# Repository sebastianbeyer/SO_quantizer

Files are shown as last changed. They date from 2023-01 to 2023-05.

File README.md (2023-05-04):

Kosmo format quantizer based largely on the [kassutronics quantizer](https://store.kassutronics.net/eurorack-diy-c-1/quantizer-p-1). 
I went for a different interface though, where you select the scale via potentiometer and with the second potentiometer (and cv input) you can bias the incoming voltages and therefore 'transpose in scale'. 
It still lacks a few scales.

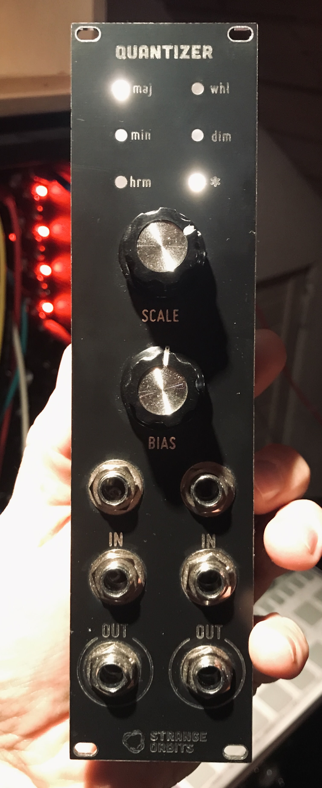
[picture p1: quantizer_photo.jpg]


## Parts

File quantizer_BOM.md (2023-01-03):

# quantizer.kicad_sch BOM

Tue 03 Jan 2023 10:16:02 CET

Generated from schematic by Eeschema 6.0.8-f2edbf62ab~116~ubuntu22.04.1

**Component Count:** 114

| Refs | Qty | Component | Description | Vendor | SKU |
| ----- | --- | ---- | --- | ---- | ---- |
| A1 | 1 | Arduino_Nano_v3.x | Arduino Nano v3.x |  |  |
| C1, C8, C15, C17 | 4 | 470p | Unpolarized capacitor |  |  |
| C2, C9, C16, C18 | 4 | 47p | Unpolarized capacitor |  |  |
| C3, C4, C10, C11 | 4 | 220p | Unpolarized capacitor |  |  |
| C5, C6, C7, C12, C13, C14 | 6 | 1n | Unpolarized capacitor |  |  |
| C19, C20, C25, C26 | 4 | 100n | Unpolarized capacitor |  |  |
| C21, C23, C24 | 3 | 10u | Polarized capacitor | Tayda |  |
| C22 | 1 | 22n | Unpolarized capacitor |  |  |
| D1, D2, D3, D4, D5, D6 | 6 | LED_red | Light emitting diode | Tayda | A-1554 |
| D7, D8 | 2 | 1N5817 | Schottky Barrier Rectifier Diode, DO-41 | Tayda | A-159 |
| J1 | 1 | cv_in_a | Audio Jack, 2 Poles (Mono / TS), Switched T Pole (Normalling) | Tayda | A-1121 |
| J2 | 1 | cv_out_a | Audio Jack, 2 Poles (Mono / TS), Switched T Pole (Normalling) | Tayda | A-1121 |
| J3 | 1 | cv_in_a_aux | Audio Jack, 2 Poles (Mono / TS), Switched T Pole (Normalling) | Tayda | A-1121 |
| J4 | 1 | cv_out_b | Audio Jack, 2 Poles (Mono / TS), Switched T Pole (Normalling) | Tayda | A-1121 |
| J5 | 1 | Conn_01x08_Male | Generic connector, single row, 01x08, script generated (kicad-library-utils/schlib/autogen/connector/) |  |  |
| J6 | 1 | Conn_01x08_Female | Generic connector, single row, 01x08, script generated (kicad-library-utils/schlib/autogen/connector/) |  |  |
| J7 | 1 | cv_in_b_aux | Audio Jack, 2 Poles (Mono / TS), Switched T Pole (Normalling) | Tayda | A-1121 |
| J8 | 1 | cv_in_b | Audio Jack, 2 Poles (Mono / TS), Switched T Pole (Normalling) | Tayda | A-1121 |
| J9 | 1 | Conn_01x06_Male | Generic connector, single row, 01x06, script generated (kicad-library-utils/schlib/autogen/connector/) |  |  |
| J10 | 1 | Conn_01x06_Female | Generic connector, single row, 01x06, script generated (kicad-library-utils/schlib/autogen/connector/) |  |  |
| J11 | 1 | Synth_power_2x5 | Pin header 2.54 mm 2x5 | Tayda | A-2939 |
| JP1, JP2 | 2 | SolderJumper_2_Open | Solder Jumper, 2-pole, open |  |  |
| Q1, Q2, Q3, Q4, Q5, Q6 | 6 | 2N3904 | Small Signal NPN Transistor, TO-92 | Tayda | A-111 |
| R1, R4, R13, R14, R15, R18, R27, R28, R29, R32, R40, R43 | 12 | *10k | Resistor | Tayda |  |
| R2, R16, R30, R41 | 4 | 10k | Resistor | Tayda |  |
| R3, R9, R17, R19, R31, R33, R42, R44, R45, R46, R47, R48, R49, R50 | 14 | 100k | Resistor | Tayda |  |
| R5, R7, R20, R22, R52 | 5 | 15k | Resistor | Tayda |  |
| R6, R8, R21, R23 | 4 | 68k | Resistor | Tayda |  |
| R10, R12, R24, R26, R34, R35, R36, R37, R38, R39 | 10 | 1k | Resistor | Tayda |  |
| R11, R25 | 2 | 1M | Resistor | Tayda |  |
| R51 | 1 | 47k | Resistor | Tayda |  |
| RV1, RV2 | 2 | 10k | Trim-potentiometer | Tayda |  |
| RV3, RV4 | 2 | 10k | Potentiometer | Tayda |  |
| RV5 | 1 | 5k | Trim-potentiometer | Tayda |  |
| U1, U2 | 2 | TL074 | Quad operational amplifier, DIP-14 | Tayda | A-1138 |
| U3 | 1 | LP2951-5.0 | Micropower Voltage Regulators with Shutdown, 100mA, Fixed Output 5.0V, LDO, DIP-8 |  |  |

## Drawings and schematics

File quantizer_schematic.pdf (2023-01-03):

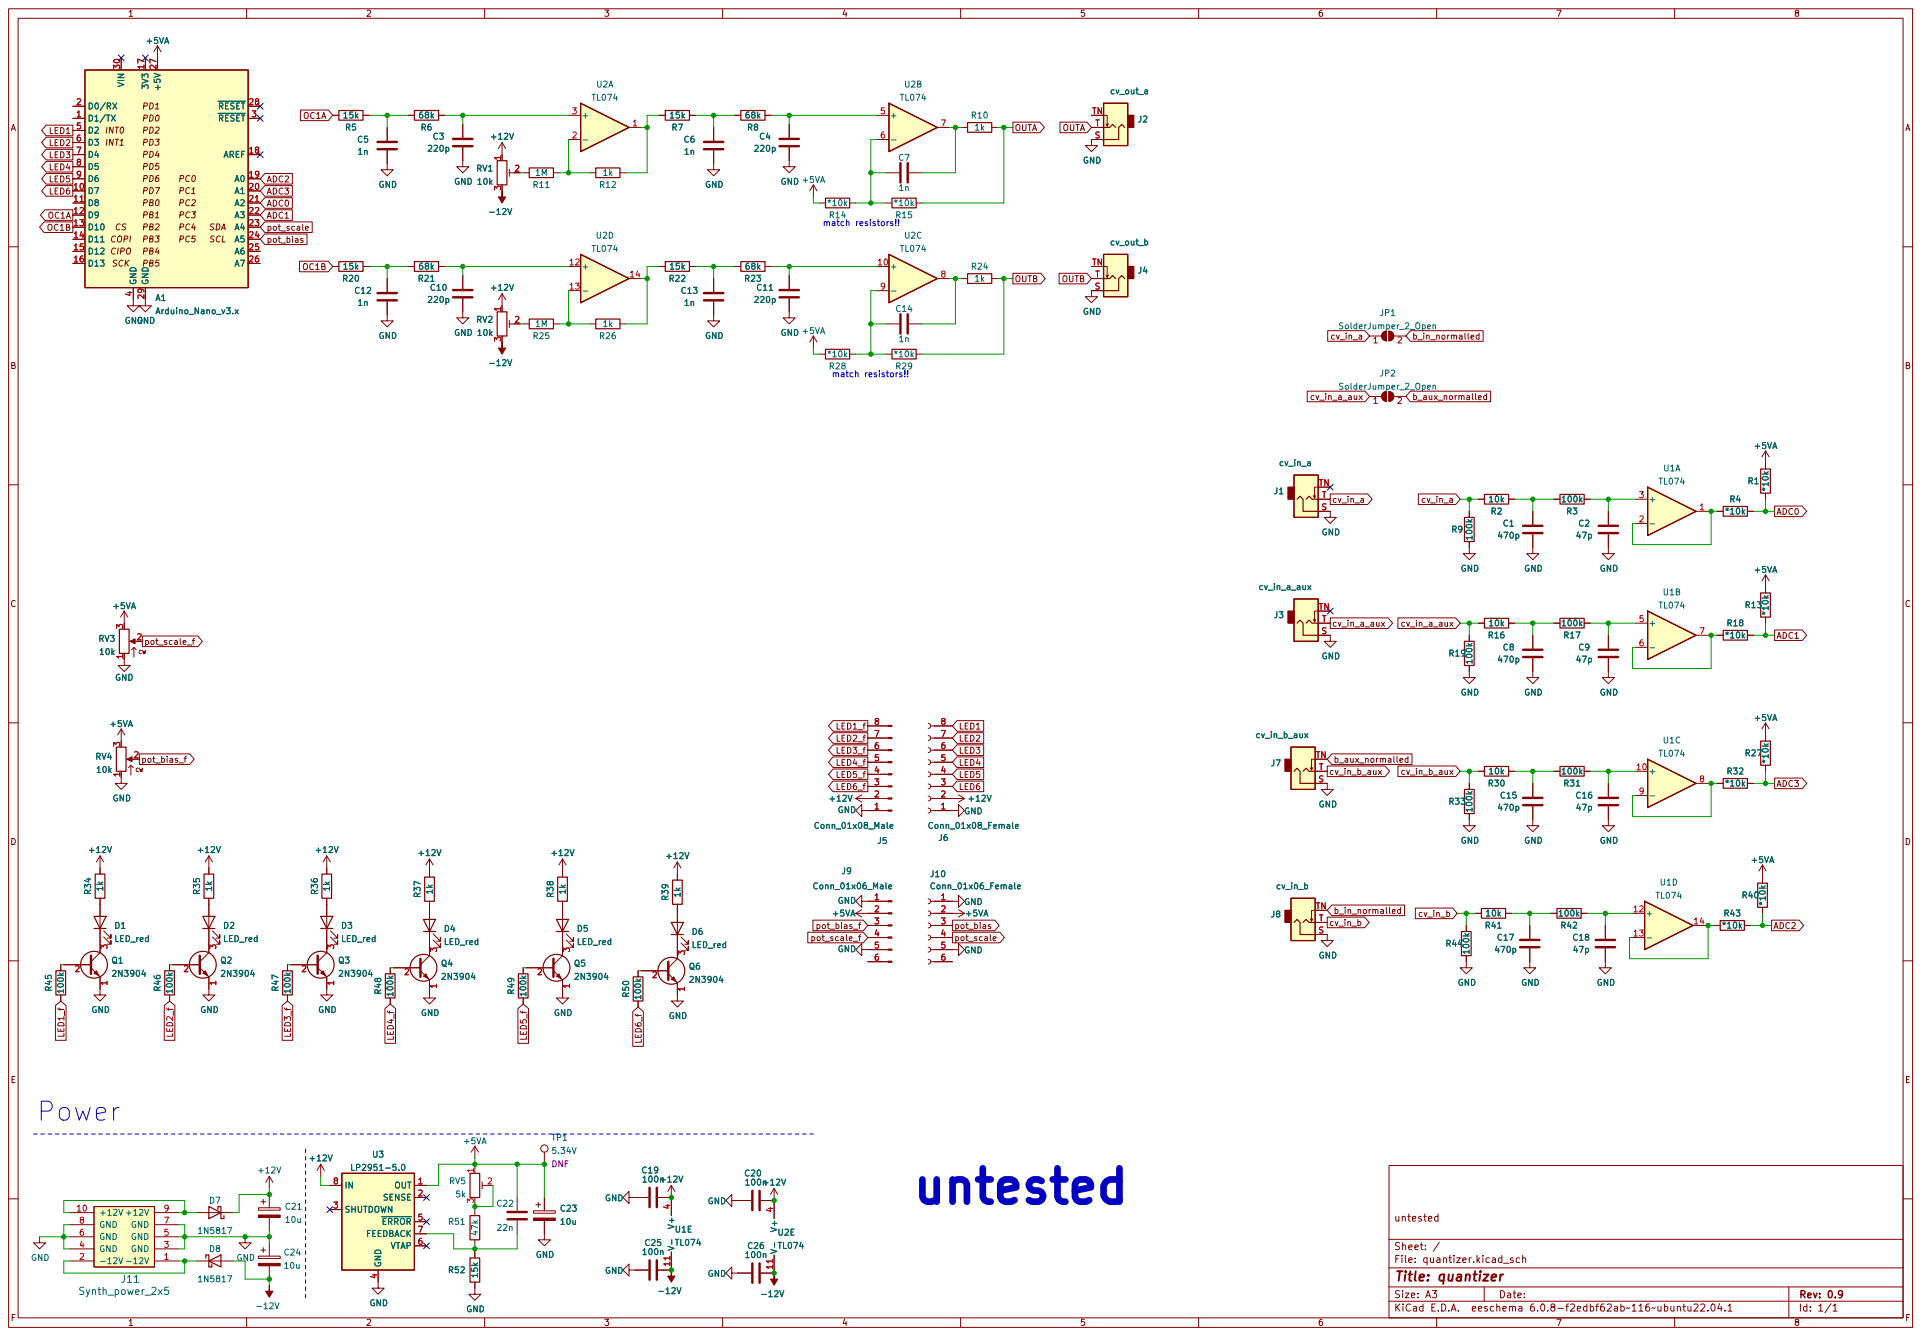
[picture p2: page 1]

match resistors!! match resistors!! GND

File: quantizer.kicad_sch Sheet: / untested

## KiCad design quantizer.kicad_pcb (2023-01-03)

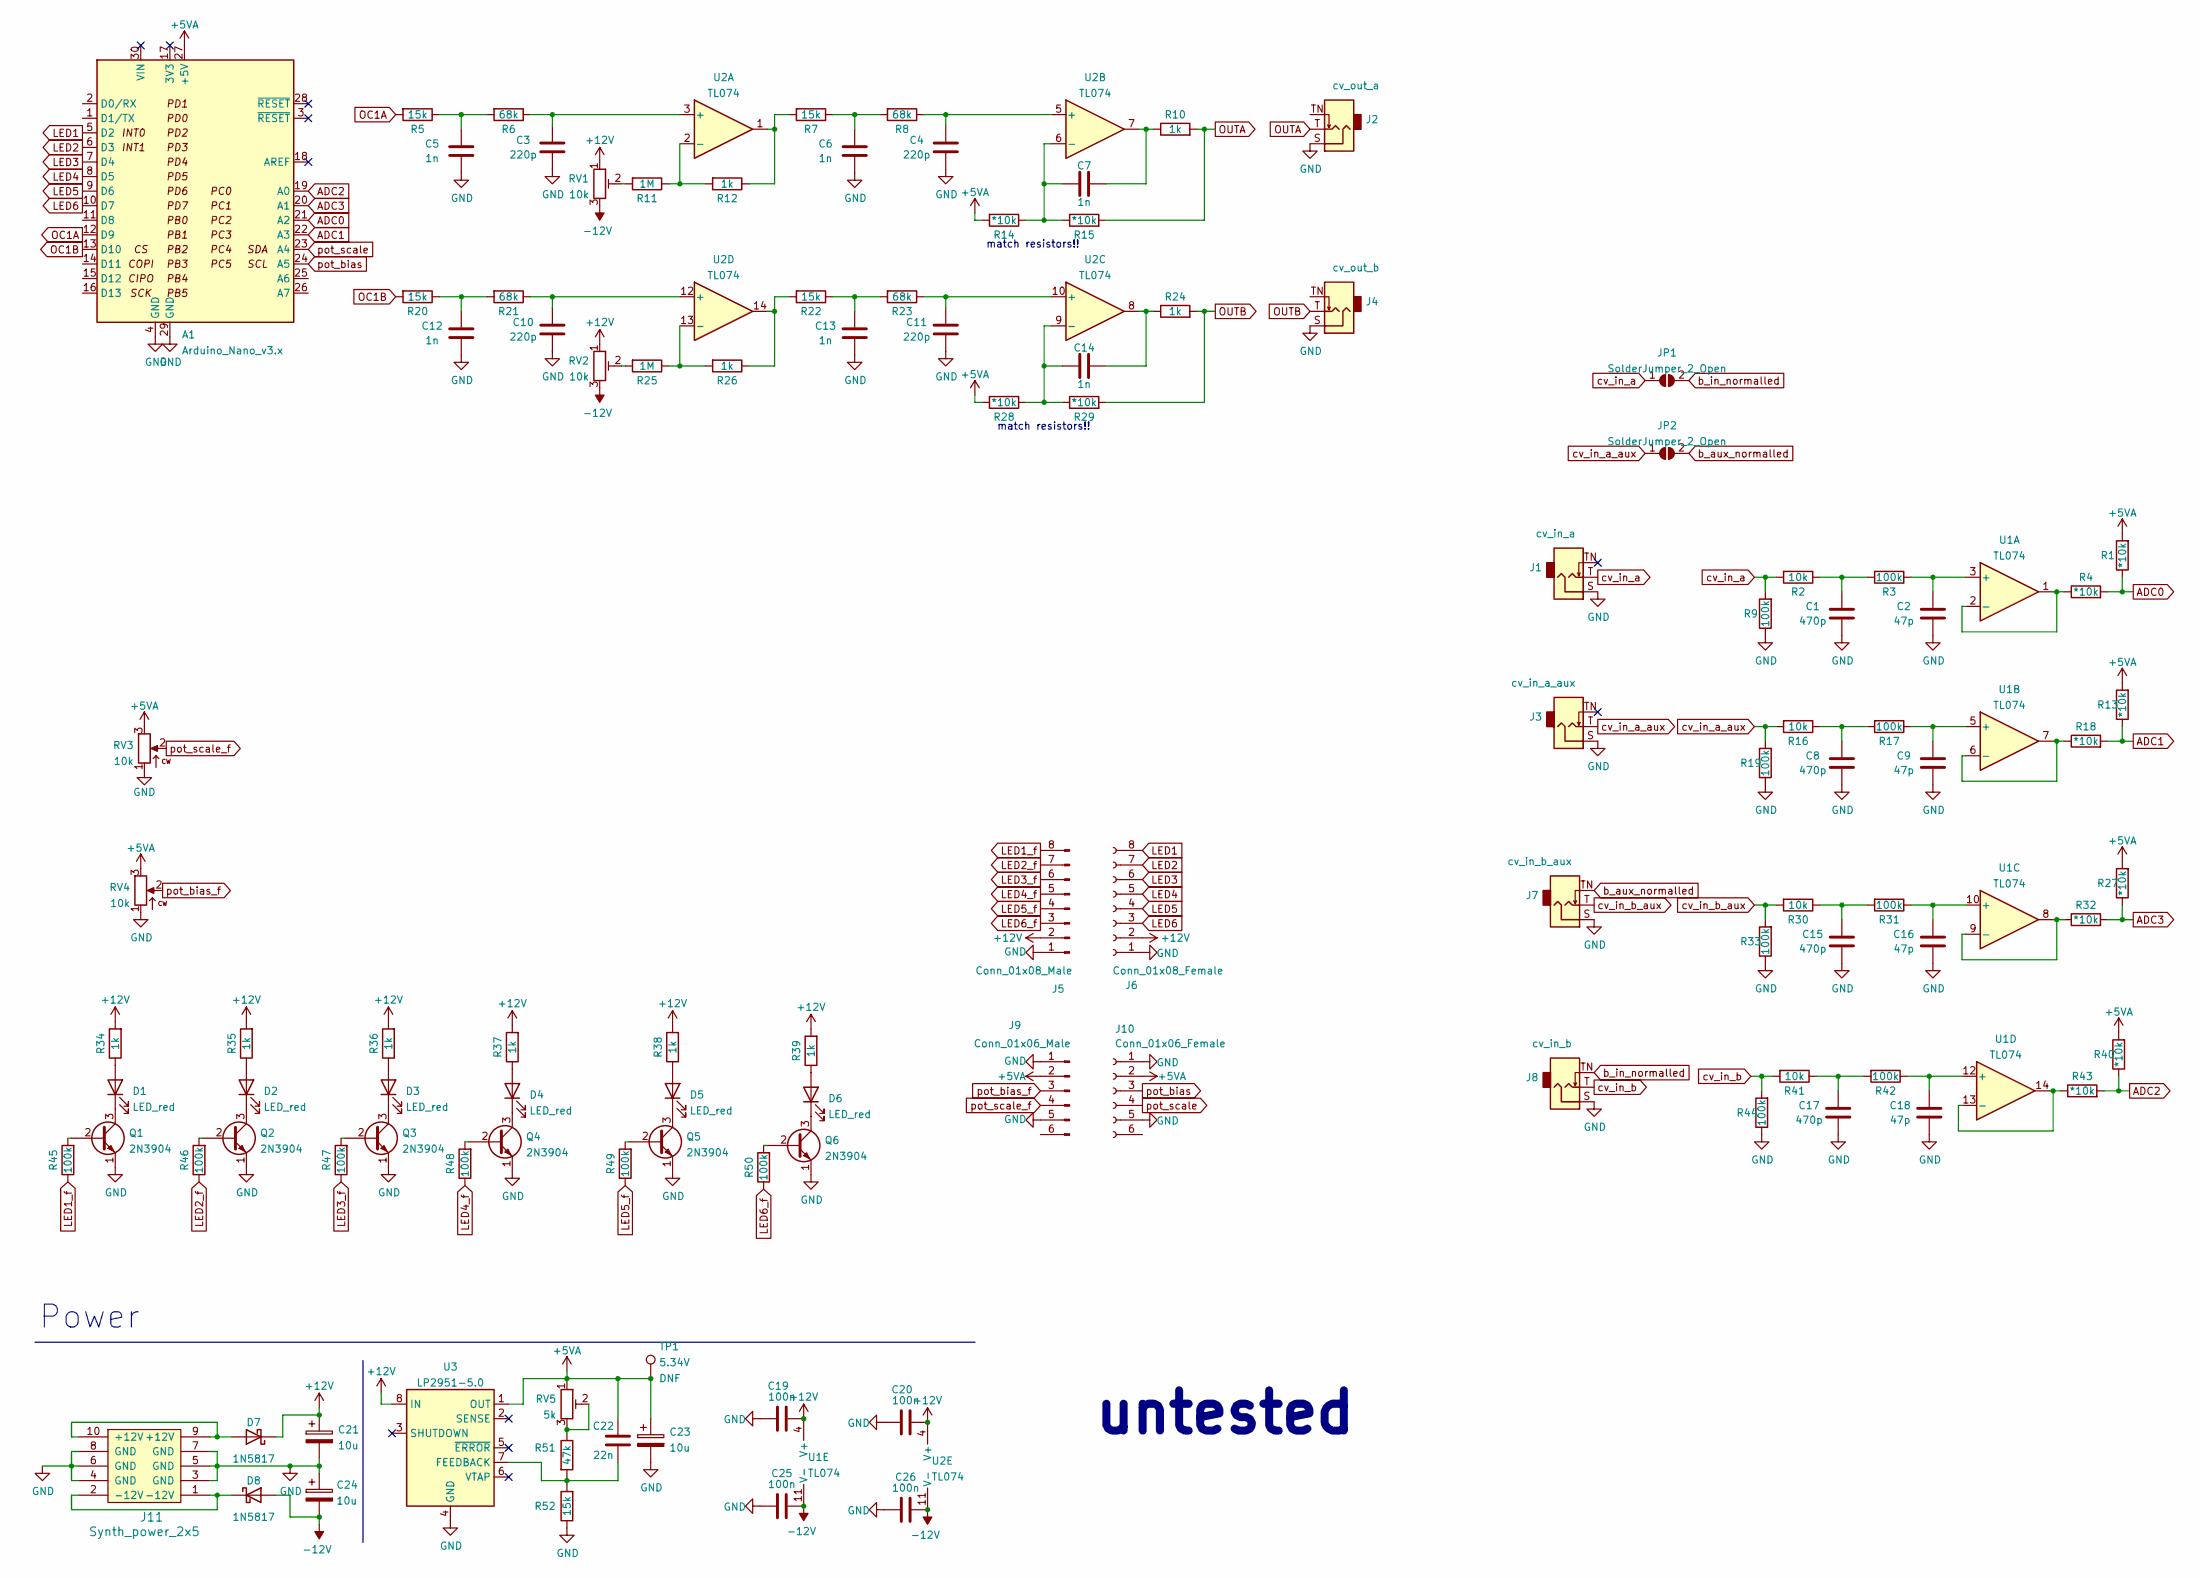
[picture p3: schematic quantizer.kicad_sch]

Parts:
A1: Arduino_Nano_v3.x; Arduino_Nano
C1, C8, C15, C17: 470p; C_Disc_D3.0mm_W1.6mm_P2.50mm
C2, C9, C16, C18: 47p; C_Disc_D3.0mm_W1.6mm_P2.50mm
C3, C4, C10, C11: 220p; C_Disc_D3.0mm_W1.6mm_P2.50mm
C5, C6, C7, C12, C13, C14: 1n; C_Disc_D3.0mm_W1.6mm_P2.50mm
C19, C20, C25, C26: 100n; C_Disc_D3.0mm_W1.6mm_P2.50mm
C21, C23, C24: 10u; CP_Radial_horizontalflat_D5mm_P2.50mm_H10mm_south
C22: 22n; C_Rect_L7.2mm_W2.5mm_P5.00mm_FKS2_FKP2_MKS2_MKP2
D1, D2, D3, D4, D5, D6: LED_red; LED_D3.0mm_FlatTop
D7, D8: 1N5817; D_DO-41_SOD81_P10.16mm_Horizontal
J1: cv_in_a; Jack_6.35mm_PJ_629HAN
J2: cv_out_a; Jack_6.35mm_PJ_629HAN
J3: cv_in_a_aux; Jack_6.35mm_PJ_629HAN
J4: cv_out_b; Jack_6.35mm_PJ_629HAN
J5: Conn_01x08_Male; PinHeader_1x08_P2.54mm_Vertical
J6: Conn_01x08_Female; PinSocket_1x08_P2.54mm_Vertical
J7: cv_in_b_aux; Jack_6.35mm_PJ_629HAN
J8: cv_in_b; Jack_6.35mm_PJ_629HAN
J9: Conn_01x06_Male; PinHeader_1x06_P2.54mm_Vertical
J10: Conn_01x06_Female; PinSocket_1x06_P2.54mm_Vertical
J11: Synth_power_2x5; Power_Header
JP1, JP2: SolderJumper_2_Open; SolderJumper-2_P1.3mm_Open_RoundedPad1.0x1.5mm
Q1, Q2, Q3, Q4, Q5, Q6: 2N3904; TO-92_Inline_Wide
R1, R4, R13, R14, R15, R18, R27, R28, R29, R32, R40, R43: *10k; R_Axial_DIN0207_L6.3mm_D2.5mm_P2.54mm_Vertical
R2, R16, R30, R41: 10k; R_Axial_DIN0207_L6.3mm_D2.5mm_P2.54mm_Vertical
R3, R9, R17, R19, R31, R33, R42, R44, R45, R46, R47, R48, R49, R50: 100k; R_Axial_DIN0207_L6.3mm_D2.5mm_P2.54mm_Vertical
R5, R7, R20, R22, R52: 15k; R_Axial_DIN0207_L6.3mm_D2.5mm_P2.54mm_Vertical
R6, R8, R21, R23: 68k; R_Axial_DIN0207_L6.3mm_D2.5mm_P2.54mm_Vertical
R10, R12, R24, R26, R34, R35, R36, R37, R38, R39: 1k; R_Axial_DIN0207_L6.3mm_D2.5mm_P2.54mm_Vertical
R11, R25: 1M; R_Axial_DIN0207_L6.3mm_D2.5mm_P2.54mm_Vertical
R51: 47k; R_Axial_DIN0207_L6.3mm_D2.5mm_P2.54mm_Vertical
RV1, RV2: 10k; Potentiometer_Bourns_3296Z_Horizontal
RV3, RV4: 10k; Potentiometer_Alpha_RD901F-40-00D_Single_Vertical_centered
RV5: 5k; Potentiometer_Bourns_3296Z_Horizontal
TP1: 5.34V; TestPoint_THTPad_D1.5mm_Drill0.7mm
U1, U2: TL074; DIP-14_W7.62mm_Socket_LongPads
U3: LP2951-5.0; DIP-8_W7.62mm_Socket_LongPads

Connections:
+5VA: A1.27 (+5V), C22.2, C23.1, J9.2, J10.2, R1.2, R13.2, R14.2, R27.2, R28.2, R40.2, RV3.3, RV4.3, RV5.1, TP1.1, U3.1 (OUT)
+12V: C19.2, C20.2, C21.1, D7.1 (K), J5.2, J6.2, R34.2, R35.2, R36.2, R37.2, R38.2, R39.2, RV1.1, RV2.1, U1.4 (V+), U2.4 (V+), U3.8 (IN)
-12V: C24.2, C25.2, C26.2, D8.2 (A), RV1.3, RV2.3, U1.11 (V-), U2.11 (V-)
ADC0: A1.21 (A2), R1.1, R4.2
ADC1: A1.22 (A3), R13.1, R18.2
ADC2: A1.19 (A0), R40.1, R43.2
ADC3: A1.20 (A1), R27.1, R32.2
GND: A1.4 (GND), A1.29 (GND), C1.1, C2.1, C3.1, C4.1, C5.1, C6.1, C8.1, C9.1, C10.1, C11.1, C12.1, C13.1, C15.1, C16.1, C17.1, C18.1, C19.1, C20.1, C21.2, C23.2, C24.1, C25.1, C26.1, J1.S, J2.S, J3.S, J4.S, J5.1, J6.1, J7.S, J8.S, J9.1, J9.5, J10.1, J10.5, J11.3 (GND), J11.4 (GND), J11.5 (GND), J11.6 (GND), J11.7 (GND), J11.8 (GND), Q1.1 (E), Q2.1 (E), Q3.1 (E), Q4.1 (E), Q5.1 (E), Q6.1 (E), R9.1, R19.1, R33.1, R44.1, R52.1, RV3.1, RV4.1, U3.4 (GND); also elsewhere on the board
LED1: A1.5 (D2), J6.8
LED1_f: J5.8, R45.1
LED2: A1.6 (D3), J6.7
LED2_f: J5.7, R46.1
LED3: A1.7 (D4), J6.6
LED3_f: J5.6, R47.1
LED4: A1.8 (D5), J6.5
LED4_f: J5.5, R48.1
LED5: A1.9 (D6), J6.4
LED5_f: J5.4, R49.1
LED6: A1.10 (D7), J6.3
LED6_f: J5.3, R50.1
unnamed: C1.2, R2.1, R3.2
unnamed: C2.2, R3.1, U1.3 (+)
unnamed: C3.2, R6.1, U2.3 (+)
unnamed: C4.2, R8.1, U2.5 (+)
unnamed: C5.2, R5.1, R6.2
unnamed: C6.2, R7.1, R8.2
unnamed: C7.1, R10.1, U2.7
unnamed: C7.2, R14.1, R15.1, U2.6 (-)
unnamed: C8.2, R16.1, R17.2
unnamed: C9.2, R17.1, U1.5 (+)
unnamed: C10.2, R21.1, U2.12 (+)
unnamed: C11.2, R23.1, U2.10 (+)
unnamed: C12.2, R20.1, R21.2
unnamed: C13.2, R22.1, R23.2
unnamed: C14.1, R24.1, U2.8
unnamed: C14.2, R28.1, R29.1, U2.9 (-)
unnamed: C15.2, R30.1, R31.2
unnamed: C16.2, R31.1, U1.10 (+)
unnamed: C17.2, R41.1, R42.2
unnamed: C18.2, R42.1, U1.12 (+)
unnamed: C22.1, R51.2, R52.2, U3.7 (FEEDBACK)
unnamed: D1.1 (K), Q1.3 (C)
unnamed: D1.2 (A), R34.1
unnamed: D2.1 (K), Q2.3 (C)
unnamed: D2.2 (A), R35.1
unnamed: D3.1 (K), Q3.3 (C)
unnamed: D3.2 (A), R36.1
unnamed: D4.1 (K), Q4.3 (C)
unnamed: D4.2 (A), R37.1
unnamed: D5.1 (K), Q5.3 (C)
unnamed: D5.2 (A), R38.1
unnamed: D6.1 (K), Q6.3 (C)
unnamed: D6.2 (A), R39.1
unnamed: D7.2 (A), J11.9 (+12V), J11.10 (+12V)
unnamed: D8.1 (K), J11.1 (-12V), J11.2 (-12V)
unnamed: Q1.2 (B), R45.2
unnamed: Q2.2 (B), R46.2
unnamed: Q3.2 (B), R47.2
unnamed: Q4.2 (B), R48.2
unnamed: Q5.2 (B), R49.2
unnamed: Q6.2 (B), R50.2
unnamed: R4.1, U1.1, U1.2 (-)
unnamed: R11.1, R12.2, U2.2 (-)
unnamed: R11.2, RV1.2
unnamed: R7.2, R12.1, U2.1
unnamed: R18.1, U1.6 (-), U1.7
unnamed: R22.2, R26.1, U2.14
unnamed: R25.1, R26.2, U2.13 (-)
unnamed: R25.2, RV2.2
unnamed: R32.1, U1.8, U1.9 (-)
unnamed: R43.1, U1.13 (-), U1.14
unnamed: R51.1, RV5.2, RV5.3
OC1A: A1.12 (D9), R5.2
OC1B: A1.13 (D10), R20.2
OUTA: J2.T, R10.2, R15.2
OUTB: J4.T, R24.2, R29.2
b_aux_normalled: J7.TN, JP2.2 (B)
b_in_normalled: J8.TN, JP1.2 (B)
cv_in_a: J1.T, JP1.1 (A), R2.2, R9.2
cv_in_a_aux: J3.T, JP2.1 (A), R16.2, R19.2
cv_in_b: J8.T, R41.2, R44.2
cv_in_b_aux: J7.T, R30.2, R33.2
pot_bias: A1.24 (A5), J10.3
pot_bias_f: J9.3, RV4.2
pot_scale: A1.23 (A4), J10.4
pot_scale_f: J9.4, RV3.2

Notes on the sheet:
untested
match resistors!!
Power

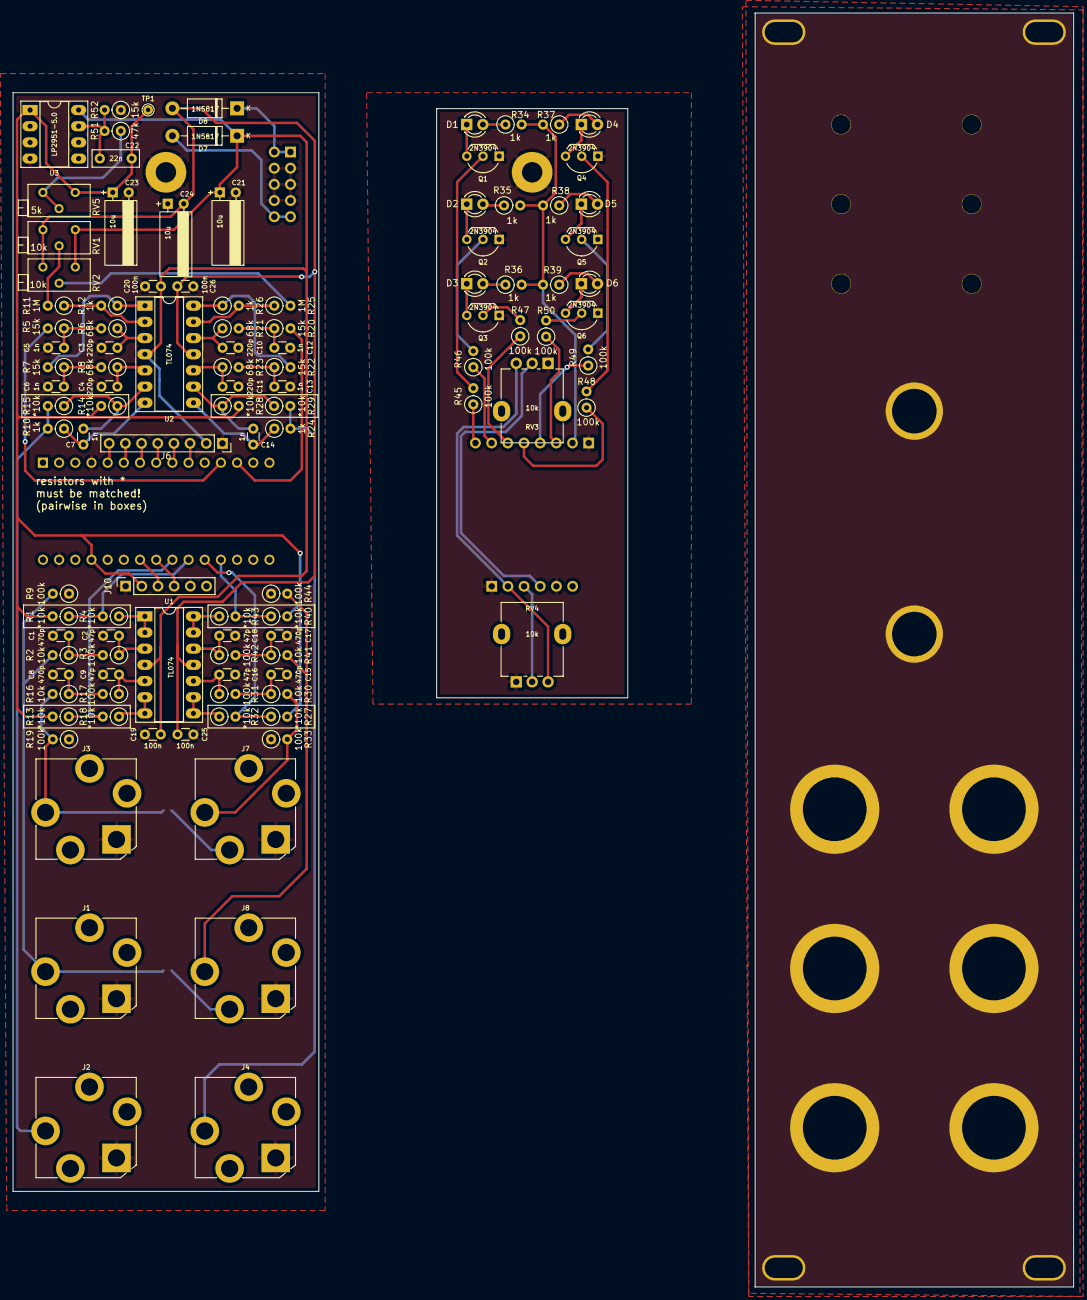
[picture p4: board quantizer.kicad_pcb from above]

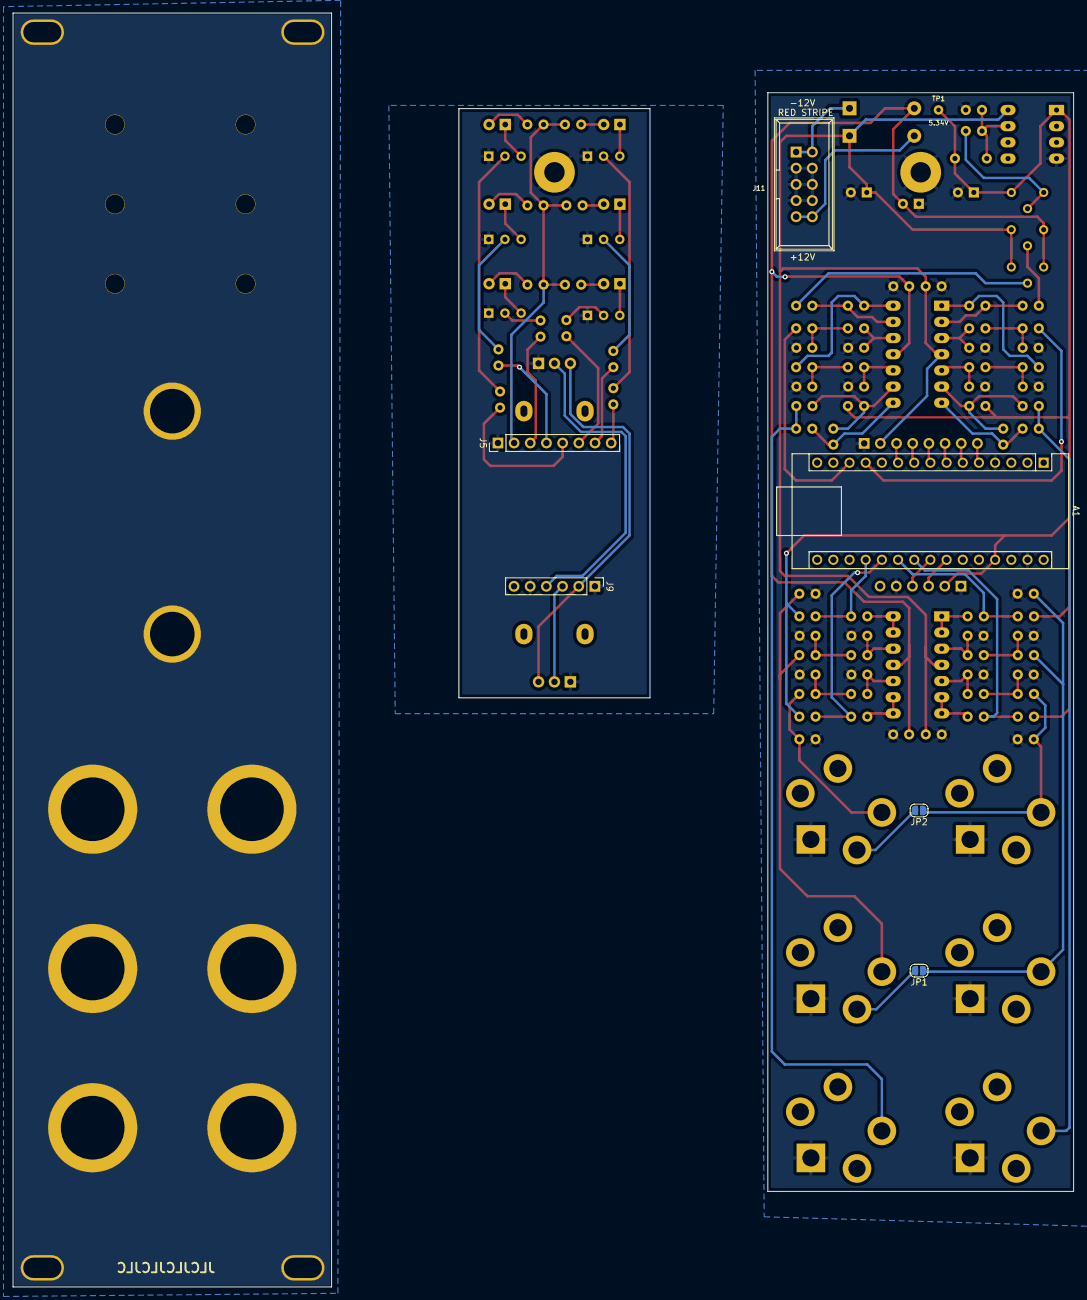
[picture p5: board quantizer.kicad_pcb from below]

Board: 2 copper layers, 166.5 x 200.0 mm, 117 parts (6 on the bottom side), 86 nets.

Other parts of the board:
 : MountingHole_3.2mm_M3_Pad
 #2: MountingHole_3.2mm_M3_Pad

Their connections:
GND: .1, #2.1; also elsewhere on the board

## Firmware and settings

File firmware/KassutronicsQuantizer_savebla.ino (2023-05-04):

// **** Debug functionality ****
/* SLOW slows down the ADC by a factor 2, giving more time for core processing. */
#define SLOW

/* DEBUG_PINS sets up the MOSI, MISO and SCK pins debug outputs 0, 1 and 2 respectively
   They can be set in code with the DEBUG_ON(i) and DEBUG_OFF(i) macros, where i = 0-2.
   Typically used for checking all kinds of timing issues  */
//#define DEBUG_PINS

/* DEBUGPRINT enables the serial port for debugging. This kind of works if you occasionally
  print something, but breaks if you try to send any significant amount of data. */
//#define DEBUGPRINT

// Set to true to reset the EEPROM to default values on startup
#define EE_RESET false

/* By default arduino sets the compiler to optimize for size. Using this pragma we can optimize
  for speed in stead. This results in a much larger binary (but still fits), but unfortunately
  no significant speed increase at all. */
//#pragma GCC optimize ("-O3")

#include "hardware.h"

volatile unsigned int autosavecounter = 0;






// **** Setup routine. All actual setup is done in Hardware.ino ****
void setup() {
  loadPersistentState();
  
  setupPWM();
  setupADC();
  setupGPIO();

  

  
  // Bit of delay after setup to allow the ADC to be properly set (probably not needed)
  delay(10);

  setupTimer();
  
  // Trigger the ADC once, should get it started
  startADC();
     
  #ifdef DEBUGPRINT
  Serial.begin(19200);
  #endif
  
  digitalWrite(LED_MAJ_PIN, HIGH);
}

// **** Main program loop ****
void loop() {
  // All important stuff runs from the ADC and Timer0 interrupts.
  // Here we have only the lowest priority process, which is initiating an autosave when needed
  //if (autosavecounter == 1) {
    //savePersistentState();
  //  autosavecounter = 0;
  //}
  //updateLEDs(possibleScales[0].ledPattern);
  //digitalWrite(LED_MAJ_PIN, HIGH);
  
}

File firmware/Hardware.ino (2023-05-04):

/* Hardware.ino
 *  This code does all the lower level hardware-related stuff, such as
 *  - Setting up registers at start up
 *  - Interrupt routines for the ADC and the UI timer
 *  - Read/write the front panel shift registers
 *  - Switch debounce and edge detection
 *  
 *  This code is heavily tied in with the hardware, and changing it requires
 *  some understanding of how the hardware is used.
 *  
 *  Higher level stuff is done in Core.ino (the actual quantiziation) and 
 *  UI.ino (defining the menu structure etc).
 */

// system constants
#define SWITCH_DEBOUNCE 10 // Switch debounce time, in IO loop counts (around 1ms)


void setupADC() {  
  // Disable ADC (just to be sure)
  cbi(ADCSRA,ADEN);

  // Choose voltage reference. 00=Aref external, 01=AVCC (5V), 11=internal 1.1V
  cbi(ADMUX,REFS1);
  sbi(ADMUX,REFS0);

  // Disable left adjust result
  cbi(ADMUX,ADLAR);
  
  // Define input channels
  // 0000 - 0111: ADC0 - ADC7
  // 1000: Temp sensor
  // 1110: 1.1V reference
  // 1111: GND
  cbi(ADMUX,MUX3);
  cbi(ADMUX,MUX2);
  cbi(ADMUX,MUX1);
  sbi(ADMUX,MUX0);



  // Enable auto trigger
  sbi(ADCSRA,ADATE); 

  // Enable interrupt
  sbi(ADCSRA,ADIE);
  
  // set prescale to 16 --> 13us per conversion
  // Note: prescale of 2 to 8 gives somehow lower resolution (not all values occur)
  // Datasheet specifies ADC clock must be max 200kHz for full resolution, but faster can be used if
  // 10-bit accuracy is not required. Prescaler = 64 would give 250kHz, probably close enough
  // Prescaler = 2^z, where z is these three bits (0 is lsb). max 128, min 2 (000 and 001 both give 2)
  // Set prescale to 64 = 52us per conversion (ADC clock 250 kHz)
  sbi(ADCSRA,ADPS2) ; //1
  sbi(ADCSRA,ADPS1) ; //1
  cbi(ADCSRA,ADPS0) ; //0

  #ifdef SLOW
  sbi(ADCSRA,ADPS2) ; //1
  sbi(ADCSRA,ADPS1) ; //1
  sbi(ADCSRA,ADPS0) ; //1
  #endif

  // Set Auto Trigger Source to free running
  // Other options: timer or external interrupt
  cbi(ADCSRB,ADTS2);
  cbi(ADCSRB,ADTS1);
  cbi(ADCSRB,ADTS0);

  // Disable digital input buffer of ADC0 and ADC1 pins (since we use them as analog)
  //cbi(DIDR0,ADC0D);
  //cbi(DIDR0,ADC1D);

  // Enable ADC 
  sbi(ADCSRA,ADEN);
}
 
void startADC() {
  sbi(ADCSRA,ADSC);
}

void setupPWM() {
  // Setup timer1 for PWM on pin 9 and 10
  
  // The pins should be outputs
  pinMode(9, OUTPUT); 
  pinMode(10, OUTPUT); 

  // --- Clock prescaler ---   
  // The PWM clock runs at the CPU rate (16 MHz) divided by a prescaler.
  // For settings 0x01 -- 0x05, the prescaler is 1, 8, 64, 256, 1024, respectively.
  // We use the fastest option:
  TCCR1B = TCCR1B & 0b11111000 | 0x01;   
  
  // --- Waveform Generation Mode (WGM)
  /* WGM13:0 sets the PWM mode. Of the 16 modes, these are most interesting:
     5 - 7: Fast PWM 8-10 bit, respectively
     14: Fast PWM, frequency set by ICR1 register
     15: Fast PWM, frequency set by OCR1A register
 
     In mode 14 and 15, the PWM frequency can be chosen very flexibly: 
  
         fPWM = fCPU / (N * (TOP+1))
  
     where fIO is the CPU clock, N is the prescaler set above and TOP is the value in
     either ICR1 or OCR1A (mode 14 or 15, resp.).
     
     We use mode 14, because then we can freely choose the frequency, but have the OCR1A register
     available to control the PWM on pin 9.
    */
  // The mode setting is spread over the two timer registers,so we set it one bit at the time (14 = 0b1110 = set set set clear)
  sbi(TCCR1B, WGM13);
  sbi(TCCR1B, WGM12);
  sbi(TCCR1A, WGM11);
  cbi(TCCR1A, WGM10);
  
  // Set ICR1 register define frequency (see formula above) and resolution (valid output values are 0 to ICR1)
  //ICR1 = 0x01FF; // 9 bit
  ICR1 = 0x007F; // 7 bit
  
  // Compare Output Mode - COM1A1, COM1A0, COM1B1, COM1B0 (first 4 bits of TCCR1A, respectively)
  // These set the mode for output A (=pin 9) and output B (=pin 10), respectively. In fast PWM mode, the modes are:
  //   0b00 - Normal port (disable PWM)
  //   0b01 - Only in WGM mode 14 or 15 (see above): Toggle output A on Compare Match. Output B is normal port (PWM disabled)
  //          I'm not sure what the point of this is. It seems you get always 50% duty cycle and half the normal fast PWM frequency,
  //          but then you can set the phase with register OCR1A (or analogWrite(9,phase) )
  //   0b10 - non-inverting PWM
  //   0b11 - inverting PWM
  // Arduinos analogWrite sets the first bit for the respective port each time you call analogWrite (so you can switch to 
  // digitalWrite and back whenever you feel like it). Let's set them all explicitly in the beginning, so we can write the
  // registers directly.
  sbi(TCCR1A, COM1A1);
  cbi(TCCR1A, COM1A0);
  sbi(TCCR1A, COM1B1);
  cbi(TCCR1A, COM1B0);
 
  // Write 0 to both ports as initial value
  OCR1A = 0;  
  OCR1B = 0;
}
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

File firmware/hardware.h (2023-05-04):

/* hardware.h
 * This file contains hardware pinout definitions as well as 
 * some macros to access I/O pins and general purpose macros 
 */

 #define SCALE_PIN A4
#define BIAS_PIN A5

#define LED_MAJ_PIN 2
#define LED_MIN_PIN 3
#define LED_HRM_PIN 4
#define LED_WHL_PIN 5
#define LED_DIM_PIN 6
#define LED_STAR_PIN 7

// Macros to set and clear a single bit in any register
#ifndef cbi
#define cbi(sfr, bit) (_SFR_BYTE(sfr) &= ~_BV(bit))
#endif
#ifndef sbi
#define sbi(sfr, bit) (_SFR_BYTE(sfr) |= _BV(bit))
#endif

// ***** Pin definitions ******
/* This code defines port names and numbers of the pins by function */

// DIN: Trigger input A
// Elsewhere code assumes Trigger B is on the same port as and one bit above Trigger A
#define DIN_PORT PORTD
#define DIN_PIN PIND
#define DIN_DDR DDRD
#define DIN_BIT 2

// GATE: Gate output A
// Elsewhere code assumes Gate B is on the same port as and one bit above Gate A
#define GATE_PORT PORTC
#define GATE_DDR DDRC
#define GATE_BIT 4

// Front panel shift register pins
// SCL: Serial CLock shared by 595 and 165
#define SCL_PORT PORTB
#define SCL_PIN PINB
#define SCL_DDR DDRB
#define SCL_BIT 0
// SDI: 165 Serial Data Input port
#define SDI_PORT PORTD
#define SDI_PIN PIND
#define SDI_DDR DDRD
#define SDI_BIT 4
// SLI: 165 latch data ouput port
#define SLI_PORT PORTD
#define SLI_PIN PIND
#define SLI_DDR DDRD
#define SLI_BIT 5
// SDO: 595 Serial Data Output port
#define SDO_PORT PORTD
#define SDO_PIN PIND
#define SDO_DDR DDRD
#define SDO_BIT 6
// SLO: 595 Latch Output port
#define SLO_PORT PORTD
#define SLO_PIN PIND
#define SLO_DDR DDRD
#define SLO_BIT 7

// **** Macros for I/O operations ****

// Macros for setting gate output
/* These are basically sbi(GATE_PORT, GATE_BIT+i) and similarly cbi,
 * however by separating the constant GATE_BIT that part of the bit shift will be done at compile time,
 * and only a shift by i (0 or 1) has to be done at runtime (AVR needs one instruction for each single bit shift).
 */
#define GATE_ON(i)  (GATE_PORT |=  ((1 << GATE_BIT) << i))
#define GATE_OFF(i) (GATE_PORT &= ~((1 << GATE_BIT) << i))

// Macro for reading the trigger input
#define DIN_READ(i) (DIN_PIN & ((1 << DIN_BIT) << i))

// DAC output macro setDAC(channel, value)
volatile unsigned int *dac_register[2] = {&OCR1A, &OCR1B};
__attribute__((always_inline)) static inline void setDAC(byte i, unsigned int value) {
  *dac_register[i] = value;
}

// Debug output pin functions
#ifdef DEBUG_PINS
#define DEBUG_ON(i) sbi(PORTB, 3+i)
#define DEBUG_OFF(i) cbi(PORTB, 3+i)
#else
#define DEBUG_ON(i) {}
#define DEBUG_OFF(i) {}
#endif

// **** Miscellaneous macros and functions ****

/* The single most processor intensive calculation we need to do is calculating modulo 12. This function does 
 * modulo 12 on byte data quickly using a single table lookup (implementation detail: it actually does modulo 3
 * after dividing by 4 using bit shifting).
 * Beware that the argument is used twice, so don't feed it complex calculations. For example don't do:
 *    byte result = mod12(a*b+c);  // Slow! a*b+c is evaluated twice.
 * but do:
 *    byte input = a*b+c;     
 *    byte result = mod12(input);  // Faster!
 */
byte mod12table[64] = {0,0,0,12,12,12,24,24,24,36,36,36,48,48,48,60,60,60,72,72,72,84,84,84,96,96,96,108,108,108,120,120,120,132,132,132,144,144,144,156,156,156,168,168,168,180,180,180,192,192,192,204,204,204,216,216,216,228,228,228,240,240,240,252};
#define mod12(value) ((value) - mod12table[(value) >> 2])


// Similar to Arduino's map function but with int datatypes, making it much faster in our application
int intmap(int x, int in_min, int in_max, int out_min, int out_max)
{
  return (x - in_min) * (out_max - out_min) / (in_max - in_min) + out_min;
}
